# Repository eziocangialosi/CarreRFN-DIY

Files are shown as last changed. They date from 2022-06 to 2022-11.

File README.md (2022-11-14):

# CarreRFN-DIY

Reproduction of an french railway signal at the 1/2 scale

# French Section (English section below) :
## Avancement du projet :
Le projet est aujourd'hui terminé ! Tout les feux sont montés et cablés. La décoration est également terminée
et la partie "intelligence" est installée et fonctionnelle.
NB : Le support qui permet de fixer le signal au mur ne sera pas référencé car adapté à mon mur.
Il vous faudra donc adapter le support à votre mur par exemple.

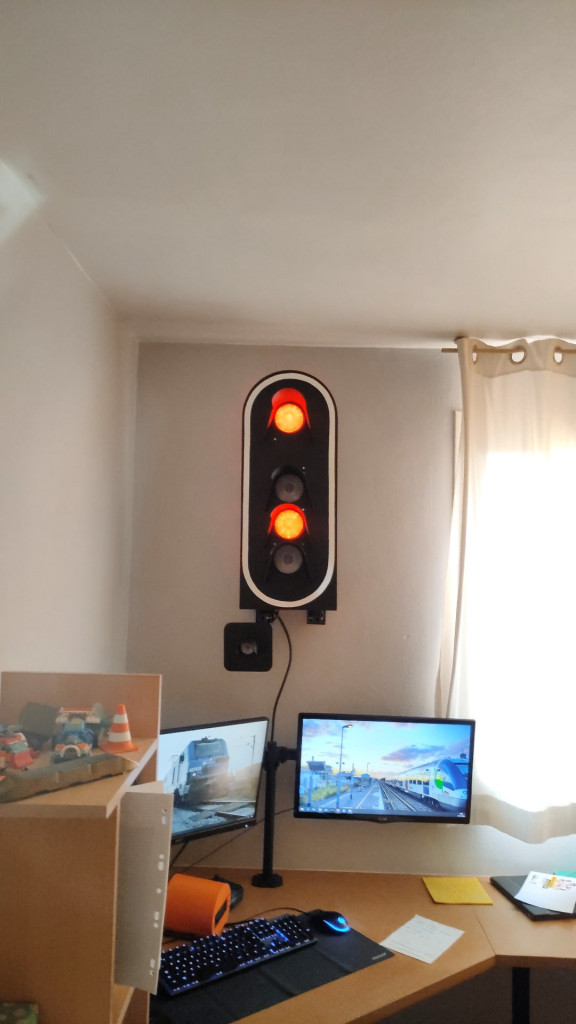
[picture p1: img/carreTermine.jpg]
Photo du carre terminé et fixé


## Objectif :
Reproduction d'un signal typique du réseau ferroviaire français à but décoratif
et à l'échelle 1/2.
Plus précisément, un "carré" à 5 feux (dont 1 bouché) plus un oeuilleton.
Le signal sera commandée à partir d'un ESP8266 et à l'aide d'une interface web, le tout
communiquant grâce au protocole MQTT.

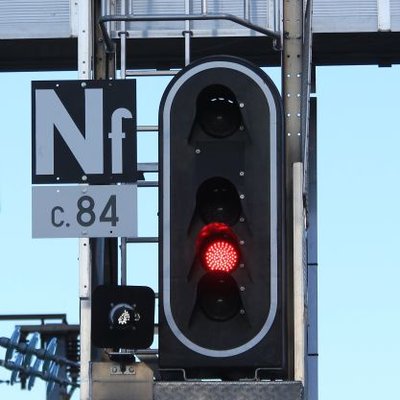
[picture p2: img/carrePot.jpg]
Photo d'un "carré" sur une potence


## Mise en plan du projet :
La première phase du projet à été sa mise en plan et modélisation 3D sous SolidWorks.

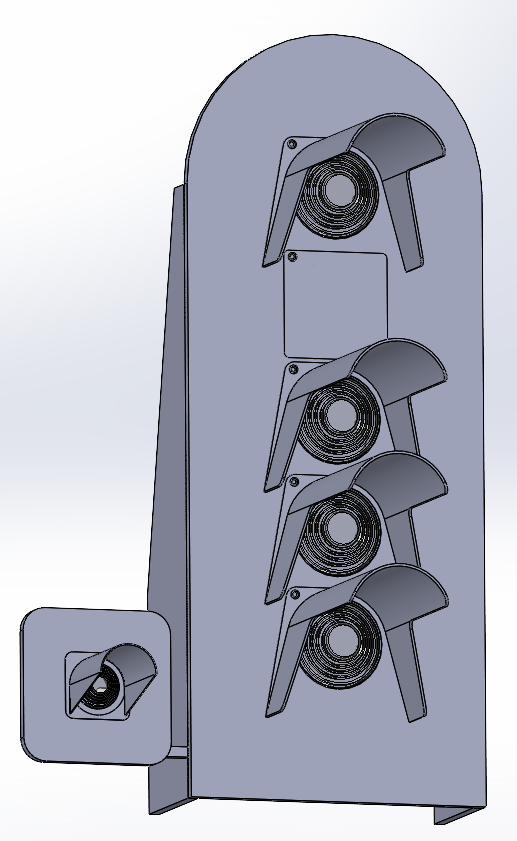
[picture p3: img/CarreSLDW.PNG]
Screenshot de la modélisation sous Soldiworks


Cette mise en plan à été faite partir de documents et plans trouvés sur internet
(rassemblés dans le dossier data)

## Réalisation :
### Cible et Oeuilleton :
La Cible et l'Oeuilleton ont été réalisés en bois puis peints en noir mat avec une bombe à peinture.

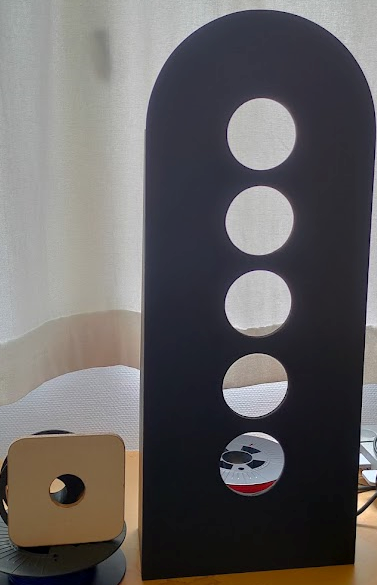
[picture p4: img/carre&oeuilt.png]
Photo de l'Oeuilleton et de la Cible


### Casquettes, diffuseurs et fonds de feux
Les casquettes qui protègent les feux ont étés réalisées grâce à l'impression 3D en PLA.
Il en est de même pour les fonds de feux. Les diffuseurs vont probalement être réalisés
également via l'impression 3D mais en PETG transparent.

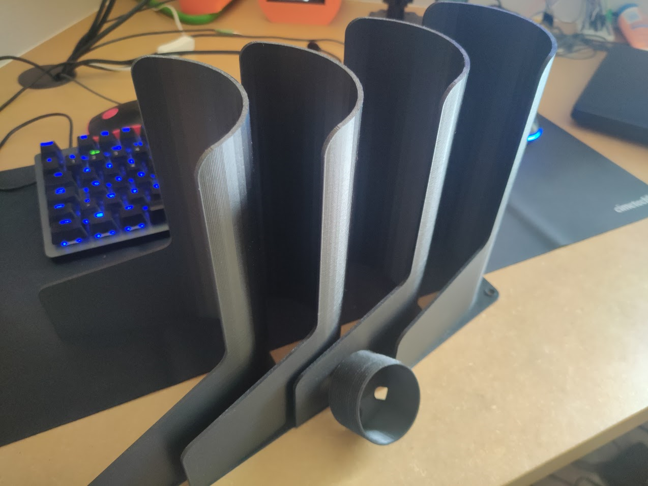
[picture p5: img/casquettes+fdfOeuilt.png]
Photo des casquettes et fond de feu de l'oeuilleton


### Lumière et partie éléctronique
L'électronique du projet s'articule autour d'un ESP8266. Du strip led adressable (WS2811) va
être utilisé faire l'allumage des feux.
NB : Des photos de la connectique choisie pour connecter les feux au faisceau éléctrique et du cablage à l'interieur des feux
sont disponibles dans le dossier "./img".

### Décorations
Le principal point de décoration sur le projet, est le contour blanc de la cible. Celui ci à été réalisé
avec du vinyle autocollant blanc découpé au scalpel. Le rendu est plutôt satisfaisant bien que un découpage
à la CNC aurait été plus propre.

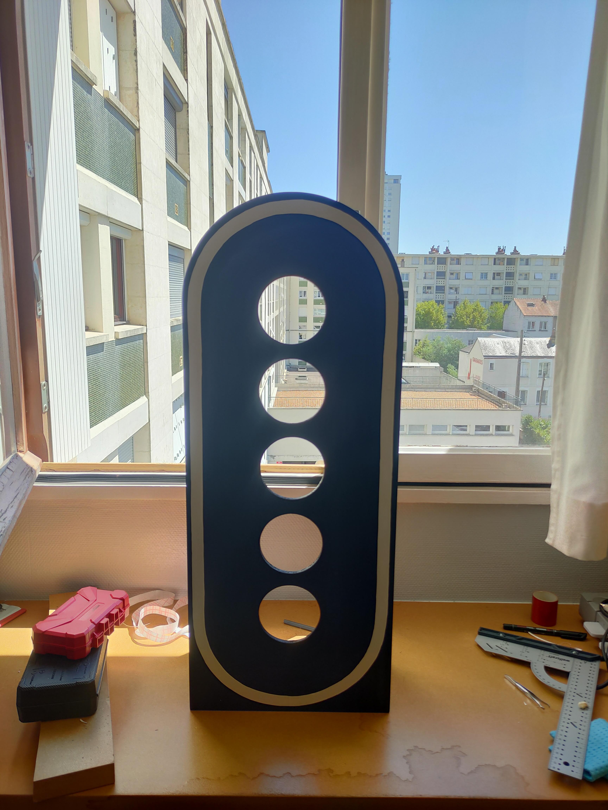
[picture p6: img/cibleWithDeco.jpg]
Photo de la cible décorée


# English Section :
## Project progreess :
Now, the project is completely finished, all the lights are mounted and wired. The decoration is also finished
and the "intelligence" part is installed and functional.
NB : The support that allows the signal to be fixed to the wall will not be referenced because it is suitable for my wall.
You will therefore have to adapt the support to your wall, for example.

Pic of the terminated project

## Goal :
Reproduction of a typical french railway network signal for decorative purposes and at the 1/2 scale.
In details, that's a "carré" with 5 lights (including 1 blocked) and one eyecup.
The signal will be command from an ESP8266 and with a web interface, all communicating through the MQTT protocol.

a carré's pic on a gallow

## Project Plan :
The first step of the project was its drawing and 3D modeling under SolidWorks.

Screenshot of 3D modeling under SolidWorks

The drawing was made from docs and plans found on internet (gathered in the data folder).

## Construction :
### Target and eyecup :
The target and the eyecup are made of wood and painted black with spray bomb.

Pic of the target and the eyecup

### Caps, diffusers and lightboxes
The caps protecting lights are made thanks to PLA 3D printing. That's the same process used for lightboxes.
The diffusers will probably also be made in 3D printing but in transparent PETG.

Pic of caps and eyecup's lightbox

### Lights and electronic part
The electronic is based around an ESP8266. For the lights, an addressable led strip (WS2811) will be used.
NB: Photos of the connectors chosen to connect the lights to the electrical harness and of the wiring inside the lights
are available in the "./img" folder.

### Decorations
The principal decoration point on the project is the blank outline of the target. This one was made
with scalpel-cut white self-adhesive vinyl. The rendering is rather satisfactory although a cutout
at the CNC would have been cleaner.

Photo of the cible decorated

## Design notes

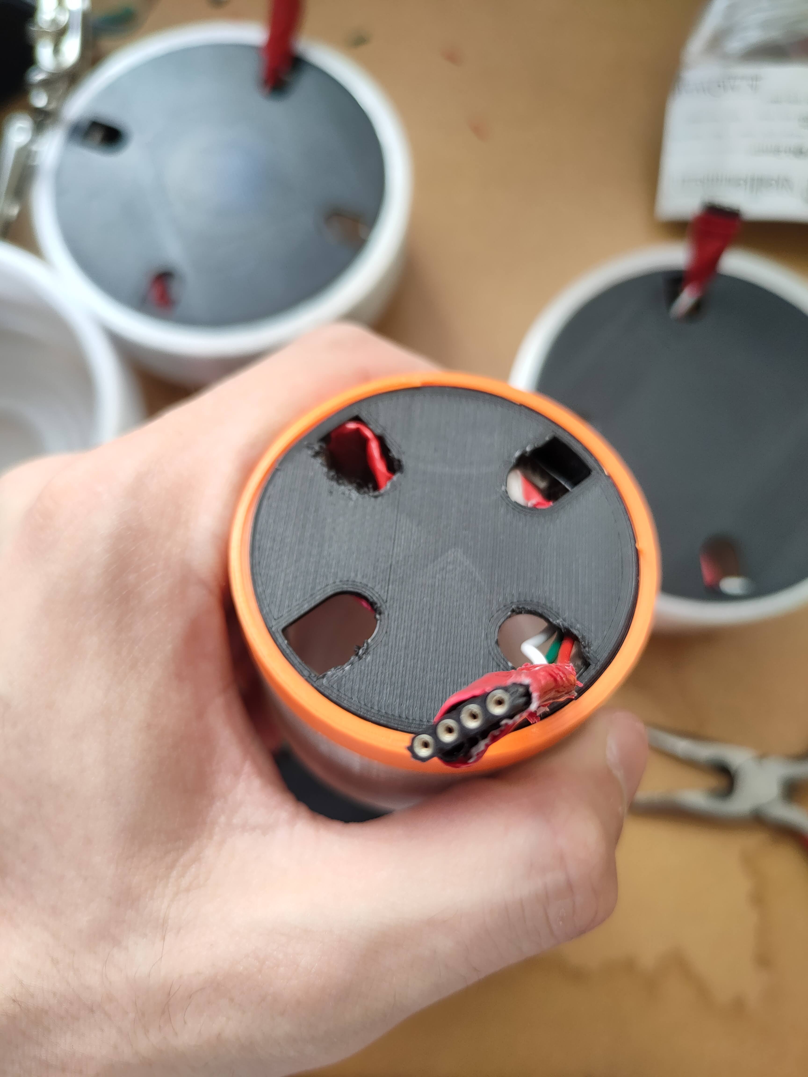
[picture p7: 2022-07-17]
img/LightConnector.jpg

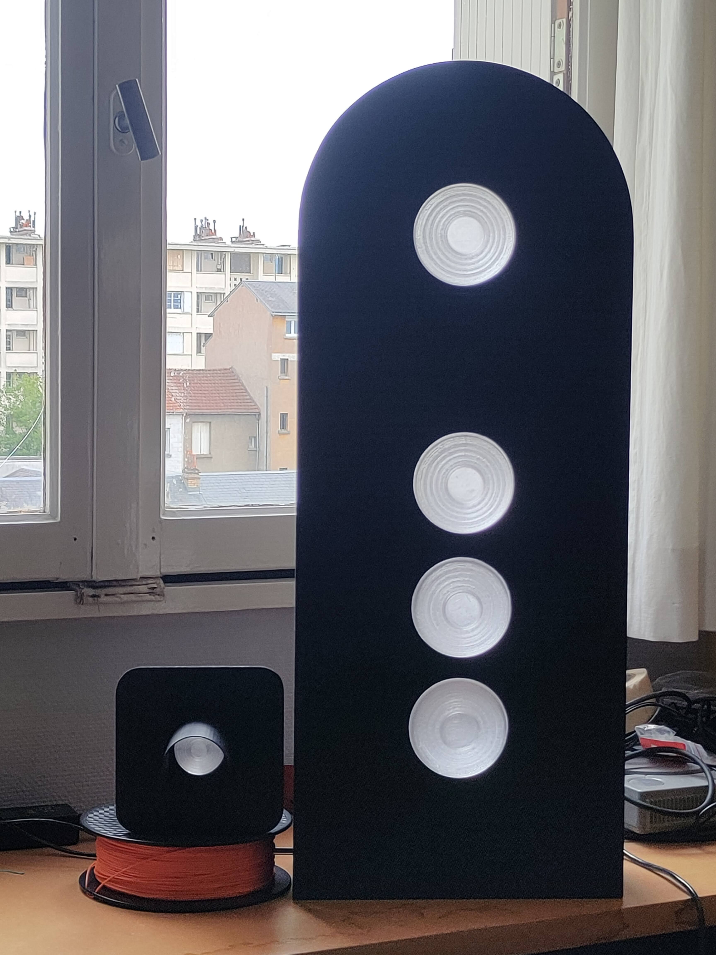
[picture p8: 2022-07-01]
img/avcmentfinjuin.jpg

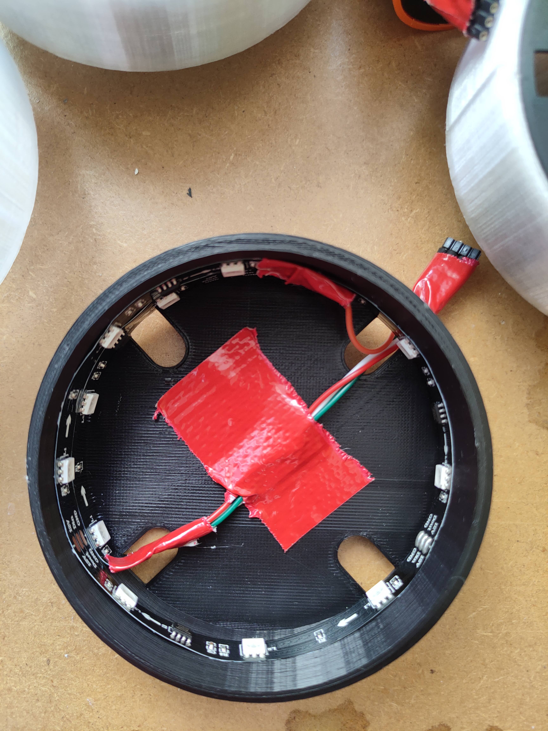
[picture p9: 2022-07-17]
img/InsideLight.jpg

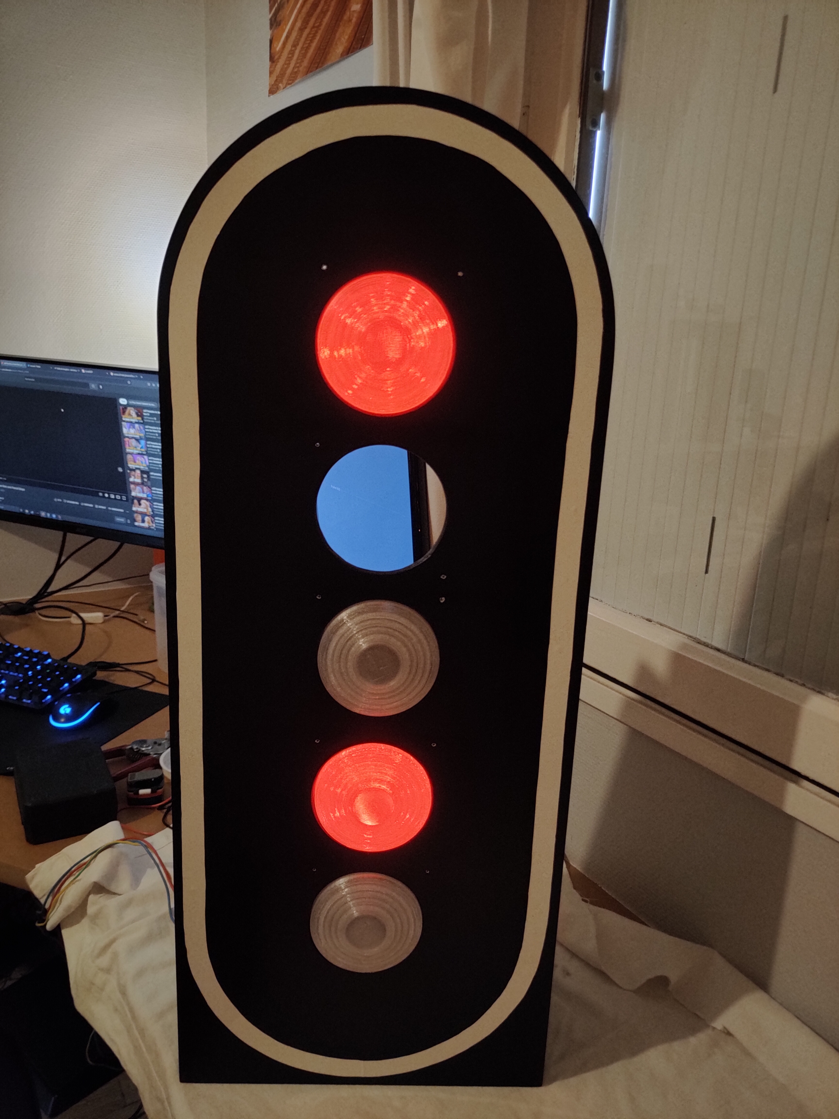
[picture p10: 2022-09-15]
img/cible98.jpg

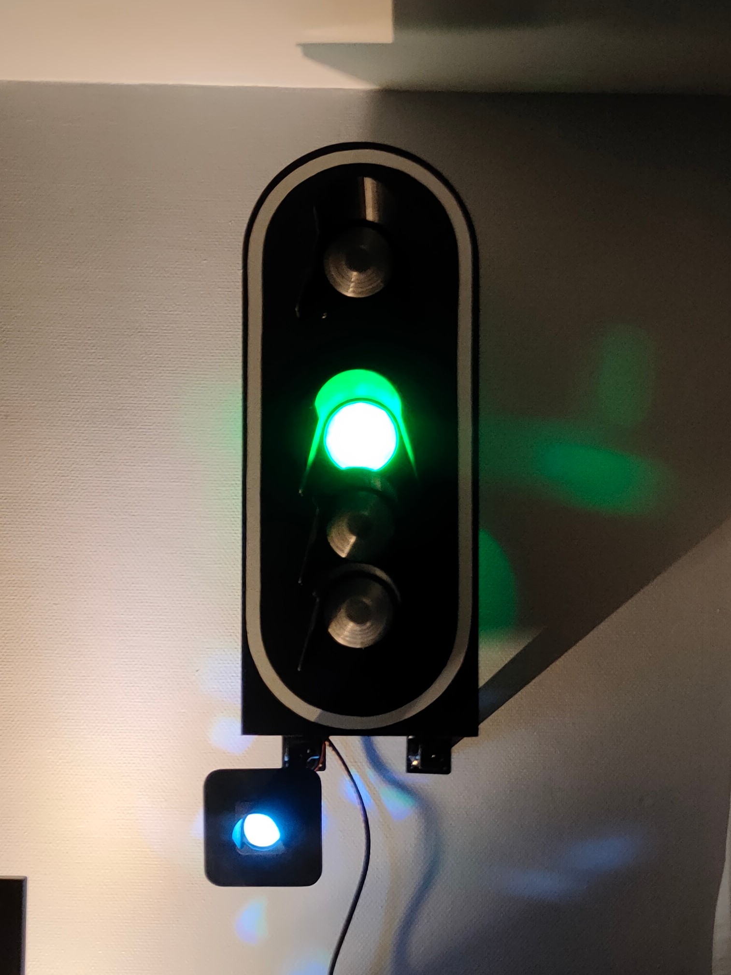
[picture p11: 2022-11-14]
img/termineVL.jpg

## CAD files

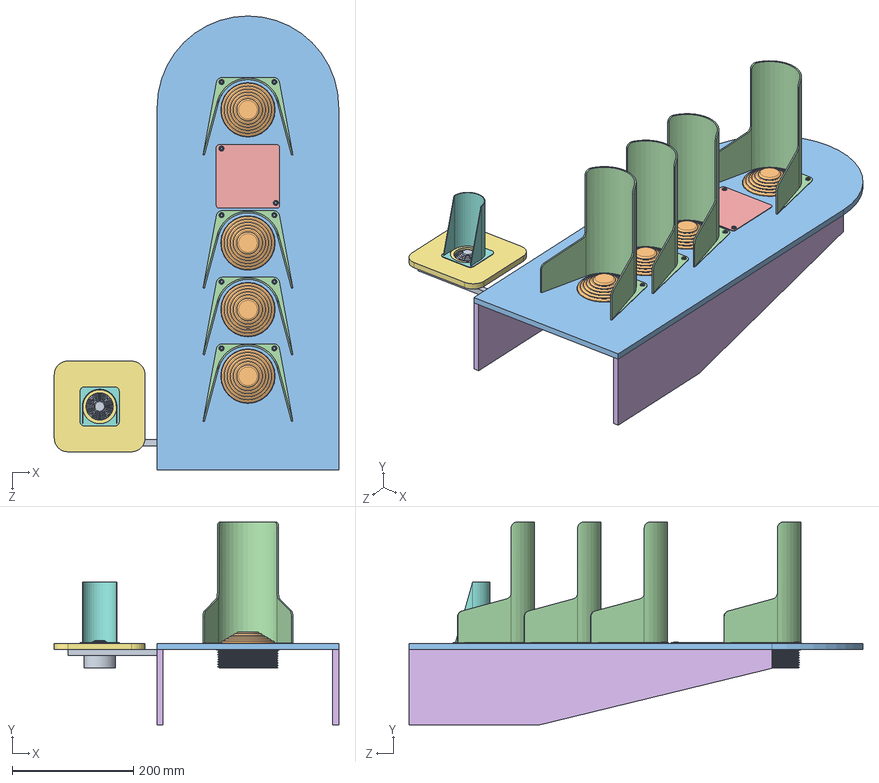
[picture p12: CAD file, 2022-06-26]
3DModels/SLDW Files/SignalRFN1,5.SLDASM
470.0 x 335.3 x 750.0 mm
CibleTypeB
CacheSoleil x 4
BoucheTrou
SideCible x 2
DiffuseurCible x 4
CibleOeuilleton
CasquetteOeuilleton
TasseauOeuilleton
FondLED x 3
DiffuseurOeuilleton
FondLEDOeuilleton

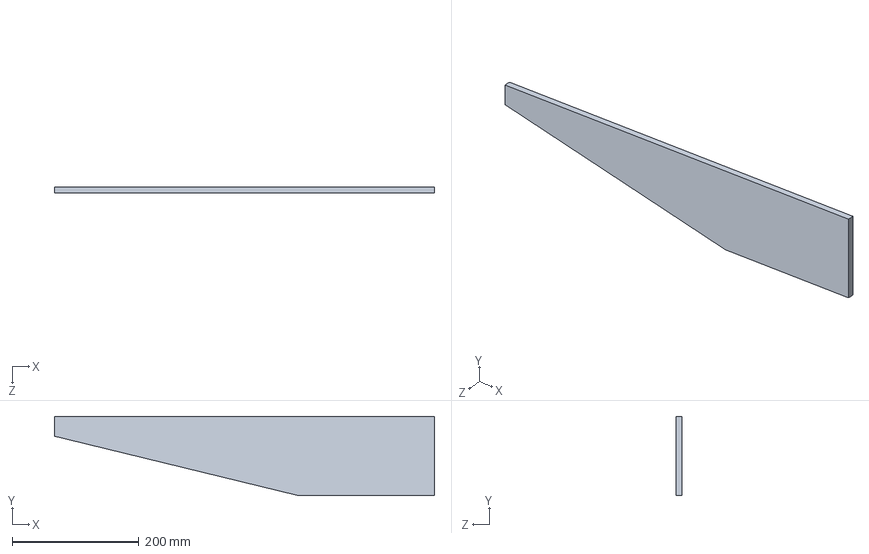
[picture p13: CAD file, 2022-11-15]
3DModels/SLDW Files/SideCible.SLDPRT
600.0 x 125.0 x 10.0 mm

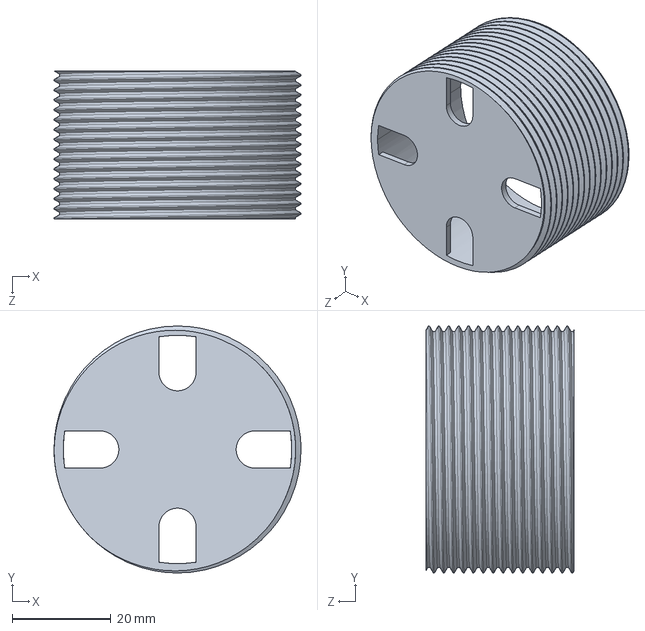
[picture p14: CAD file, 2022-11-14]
3DModels/STEP Files/FondLEDOeuilleton.STEP
50.0 x 50.0 x 30.0 mm

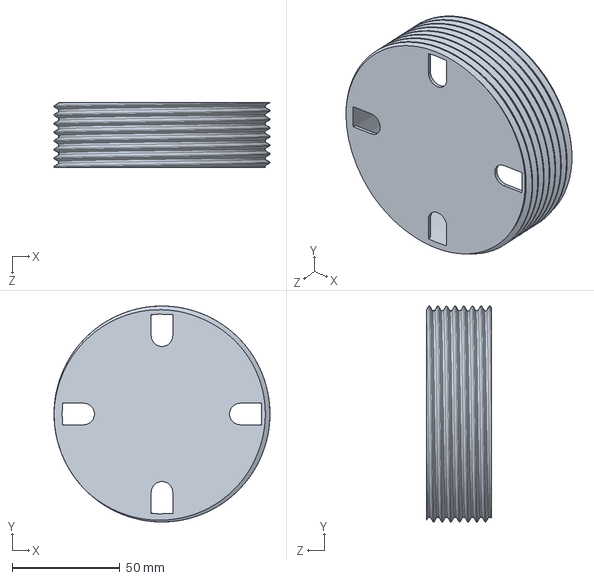
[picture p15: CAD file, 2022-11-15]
3DModels/SLDW Files/FondLED.SLDPRT
100.0 x 100.0 x 30.0 mm

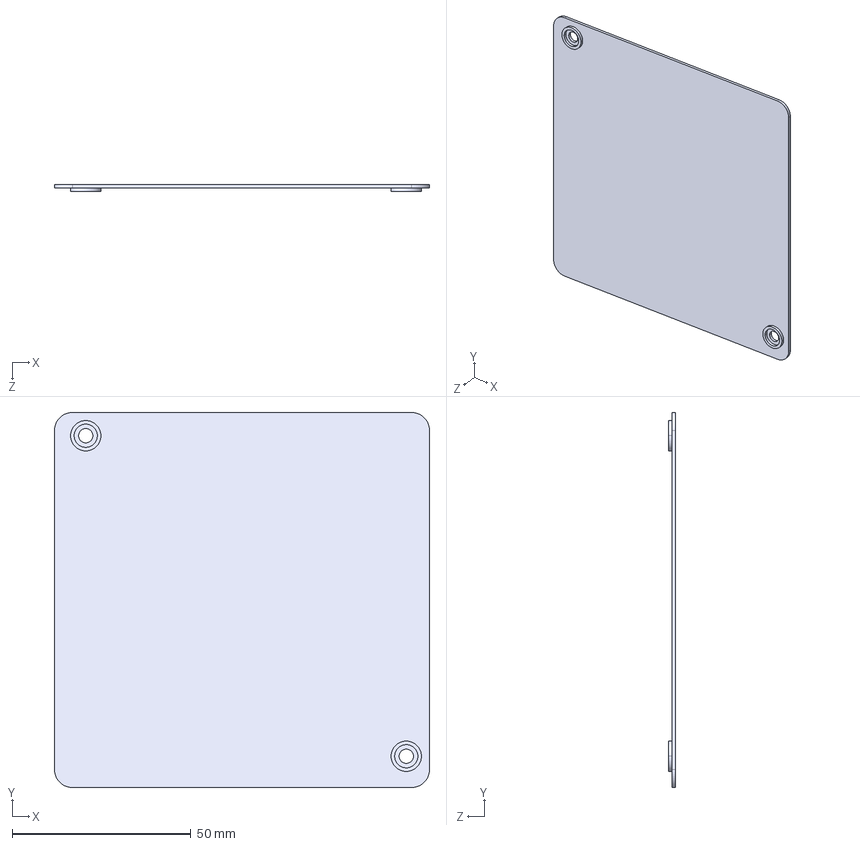
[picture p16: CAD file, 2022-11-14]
3DModels/STEP Files/BoucheTrou.STEP
105.0 x 105.0 x 2.00 mm

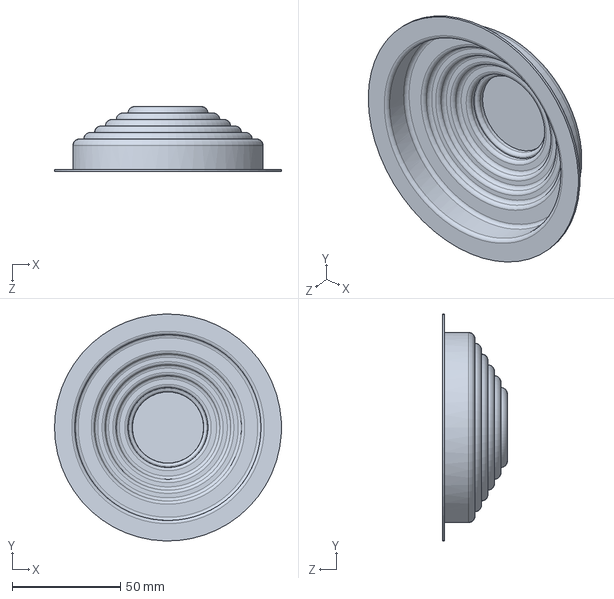
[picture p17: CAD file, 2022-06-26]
3DModels/SLDW Files/DiffuseurCible.SLDPRT
105.0 x 105.0 x 30.0 mm

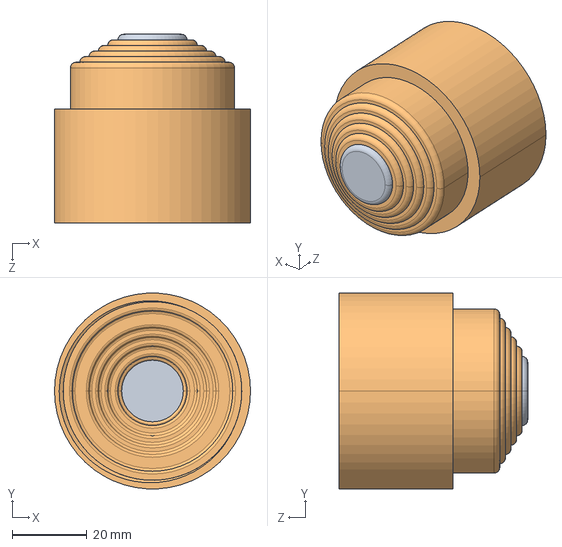
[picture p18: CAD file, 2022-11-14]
3DModels/STEP Files/DiffuseurOeuilleton.STEP
52.5 x 52.4 x 50.5 mm

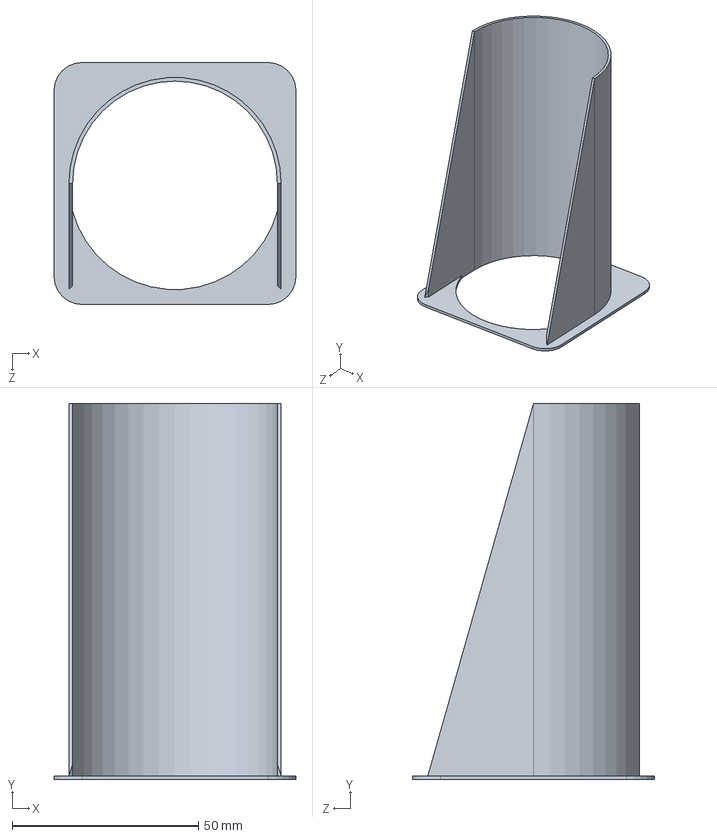
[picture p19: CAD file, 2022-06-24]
3DModels/SLDW Files/CasquetteOeuilleton.SLDPRT
65.0 x 101.0 x 65.0 mm

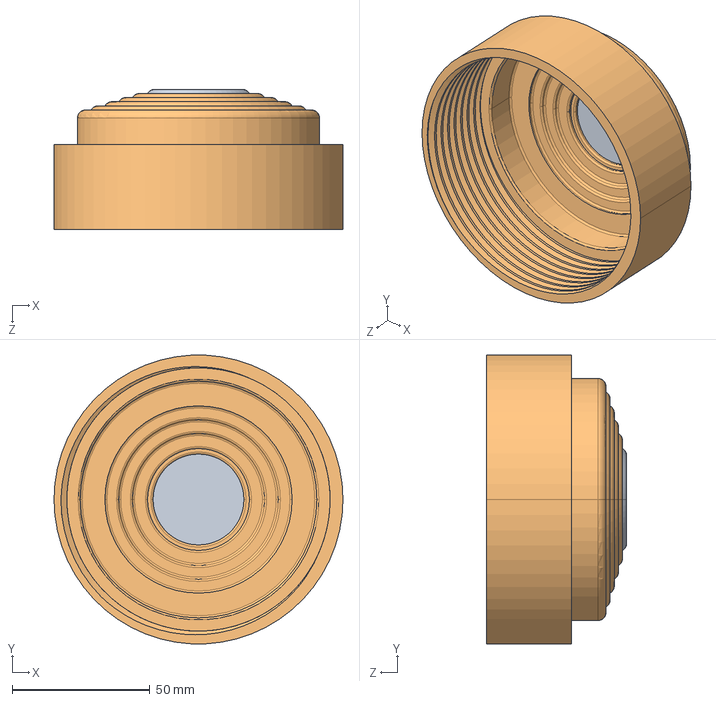
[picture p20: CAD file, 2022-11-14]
3DModels/STEP Files/DiffuseurCible.STEP
105.0 x 104.8 x 51.0 mm

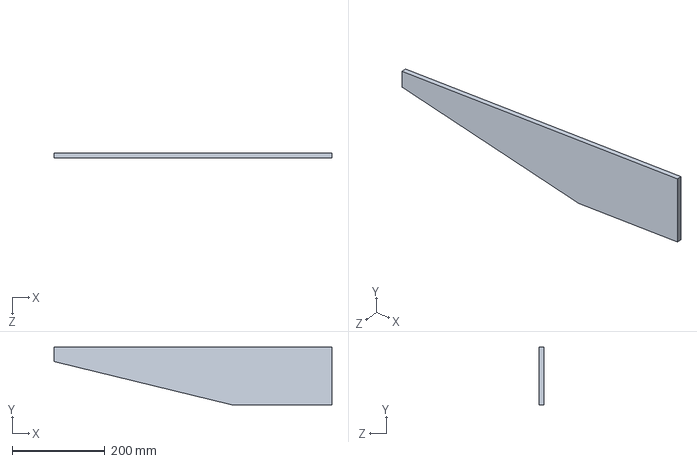
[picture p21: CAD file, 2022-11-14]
3DModels/STEP Files/SideCible.STEP
600.0 x 125.0 x 10.0 mm

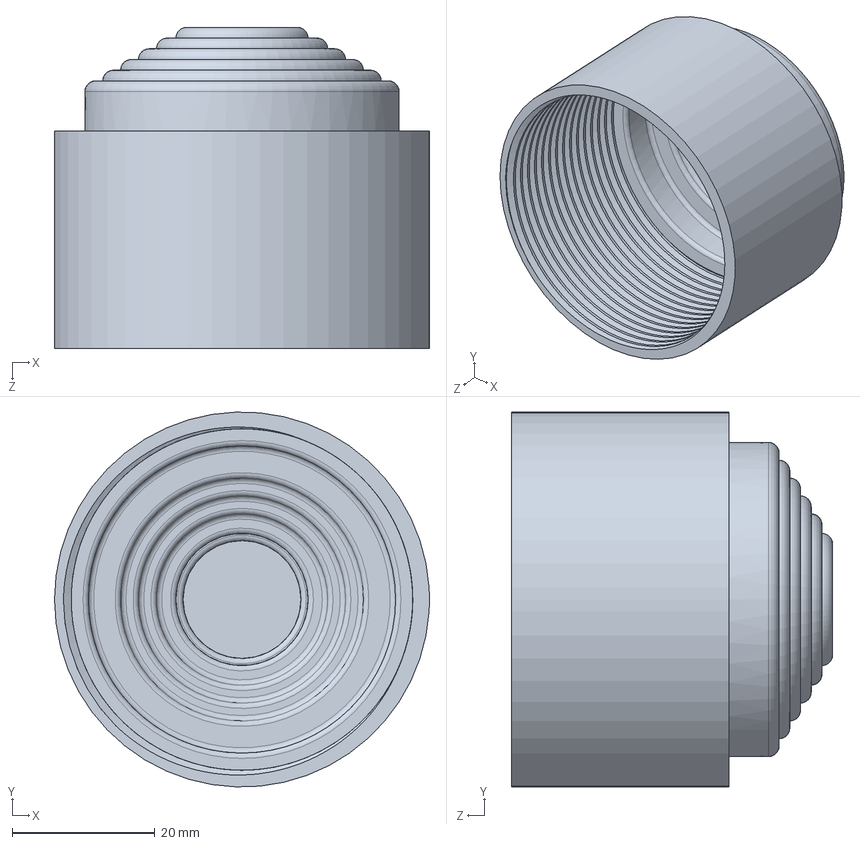
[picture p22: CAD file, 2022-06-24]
3DModels/SLDW Files/DiffuseurOeuilleton.SLDPRT
52.5 x 52.5 x 45.0 mm

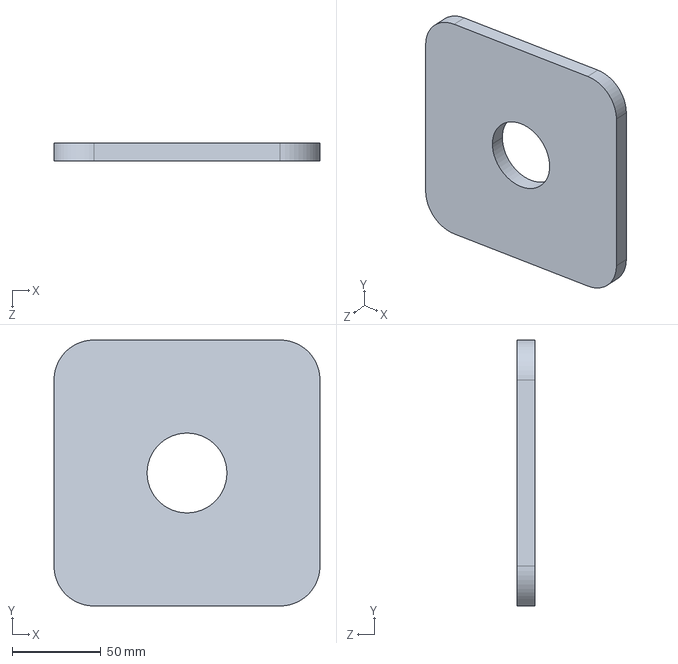
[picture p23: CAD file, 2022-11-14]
3DModels/STEP Files/CibleOeuilleton.STEP
150.0 x 150.0 x 10.0 mm

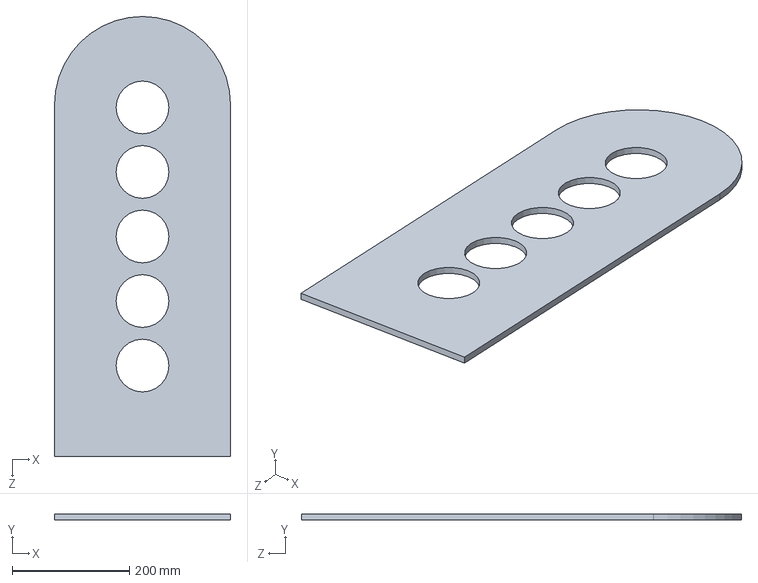
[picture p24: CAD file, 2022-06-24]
3DModels/SLDW Files/CibleTypeB.SLDPRT
300.0 x 10.0 x 750.0 mm

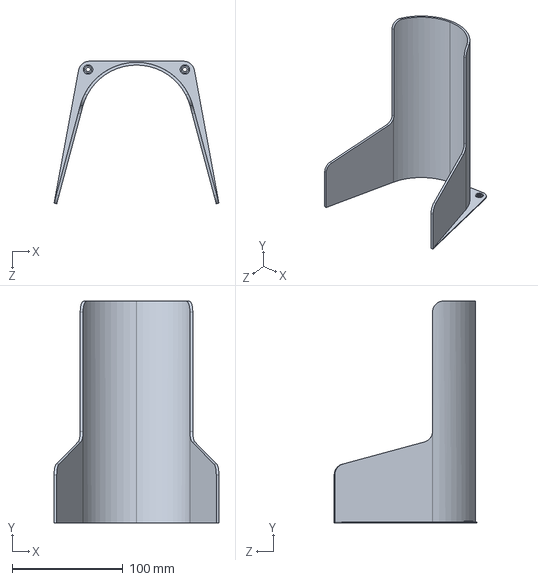
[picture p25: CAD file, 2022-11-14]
3DModels/STEP Files/CacheSoleil.STEP
148.5 x 200.0 x 128.5 mm

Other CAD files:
3DModels/STEP Files/FondLED.STEP
3DModels/SLDW Files/TasseauOeuilleton.SLDPRT
3DModels/SLDW Files/CacheSoleil.SLDPRT
3DModels/STEP Files/CasquetteOeuilleton.STEP
3DModels/SLDW Files/BoucheTrou.SLDPRT
3DModels/SLDW Files/CibleOeuilleton.SLDDRW
3DModels/SLDW Files/CibleOeuilleton.SLDPRT
3DModels/SLDW Files/FondLEDOeuilleton.SLDPRT
3DModels/SLDW Files/SignalRFN1,5.SLDDRW
3DModels/STEP Files/CibleTypeB.STEP
3DModels/STL Files/BoucheTrou.STL
3DModels/STL Files/CacheSoleil.STL
3DModels/STL Files/CasquetteOeuilleton.STL
3DModels/STL Files/CibleOeuilleton.STL
3DModels/STL Files/CibleTypeB.STL
3DModels/STL Files/DiffuseurCible.STL
3DModels/STL Files/DiffuseurOeuilleton.STL
3DModels/STL Files/FondLED.STL
3DModels/STL Files/FondLEDOeuilleton.STL
3DModels/STL Files/SideCible.STL

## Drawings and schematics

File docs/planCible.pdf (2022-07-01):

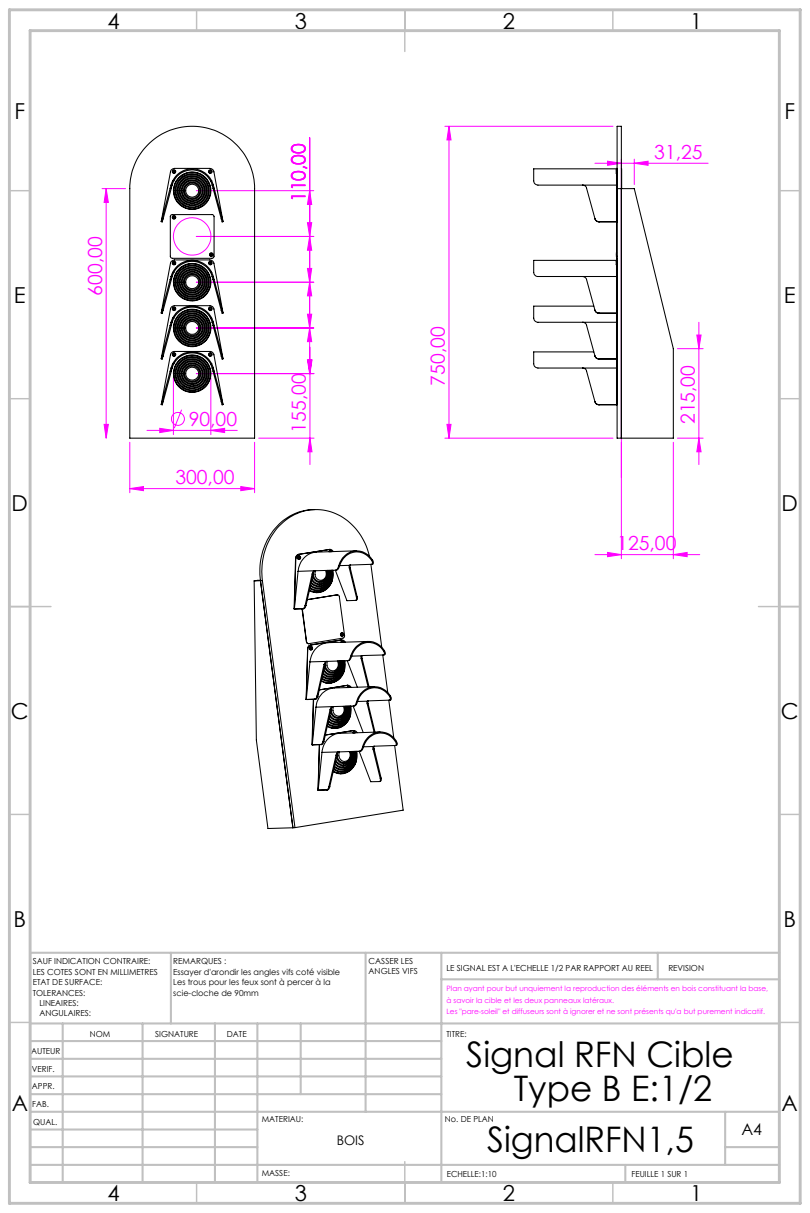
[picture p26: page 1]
CASSER LES ANGLES VIFS; LE SIGNAL EST A L'ECHELLE 1/2 PAR RAPPORT AU REEL; REVISION; ECHELLE:1:10; FEUILLE 1 SUR 1

SAUF INDICATION CONTRAIRE:
LES COTES SONT EN MILLIMETRES
ETAT DE SURFACE:
TOLERANCES:
LINEAIRES:
ANGULAIRES:

REMARQUES :
Essayer d'arondir les angles vifs coté visible
Les trous pour les feux sont à percer à la
scie-cloche de 90mm

Plan ayant pour but unquiement la reproduction des éléments en bois constituant la base,
à savoir la cible et les deux panneaux latéraux.
Les "pare-soleil" et diffuseurs sont à ignorer et ne sont présents qu'a but purement indicatif.

NOM | SIGNATURE | DATE | | | | TITRE: Signal RFN Cible Type B E:1/2

AUTEUR
VERIF.
APPR.
FAB.
QUAL. | | | | MATERIAU: BOIS | No. DE PLAN SignalRFN1,5 | A4

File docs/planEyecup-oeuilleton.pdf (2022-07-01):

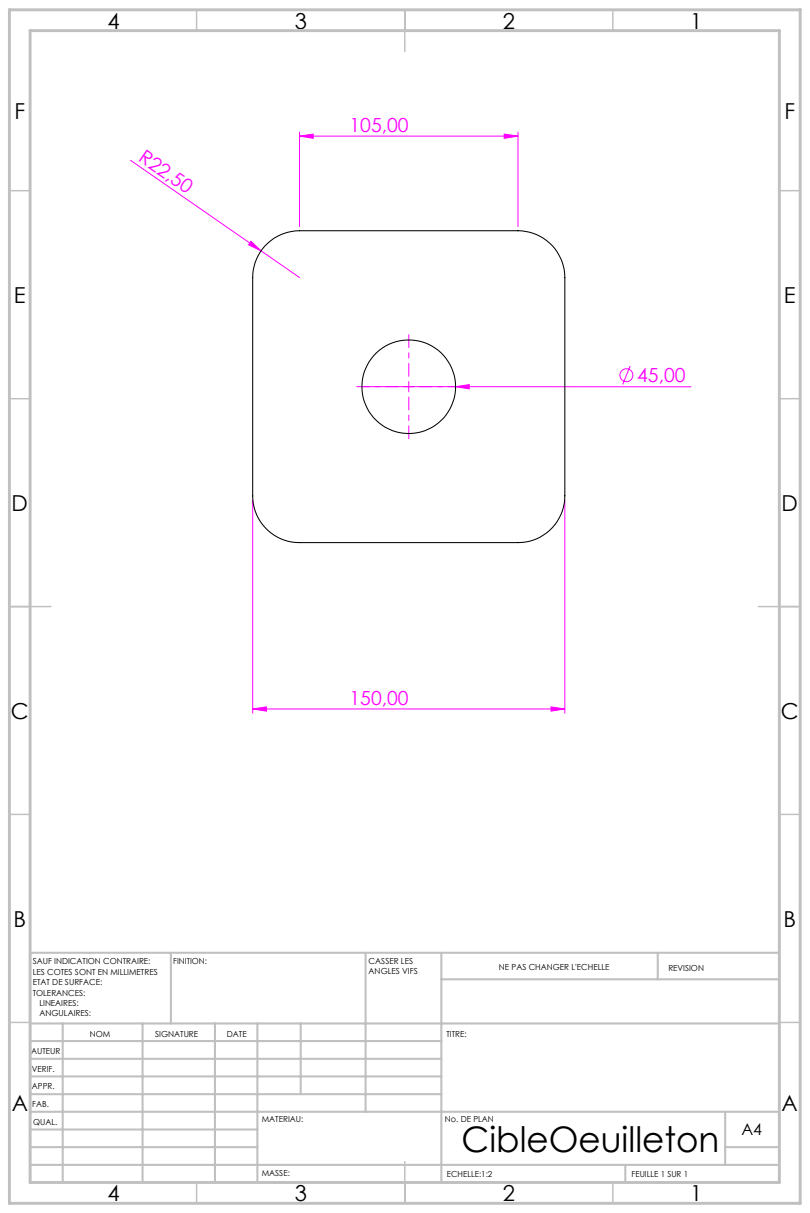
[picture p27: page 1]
FINITION:; CASSER LES; ANGLES VIFS; NE PAS CHANGER L'ECHELLE; REVISION; ECHELLE:1:2; FEUILLE 1 SUR 1

SAUF INDICATION CONTRAIRE:
LES COTES SONT EN MILLIMETRES
ETAT DE SURFACE:
TOLERANCES:
LINEAIRES:
ANGULAIRES:

NOM | SIGNATURE | DATE | | | | TITRE:

AUTEUR
VERIF.
APPR.
FAB.
QUAL. | | | | MATERIAU: | No. DE PLAN CibleOeuilleton | A4

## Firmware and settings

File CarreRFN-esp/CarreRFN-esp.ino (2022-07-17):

//CarreMQTT Version 1.0 Beta, Ezio Cangialosi, 2022

#include <ESP8266WiFi.h>
#include <PubSubClient.h>
#include <Adafruit_NeoPixel.h>

#define OUTTOPIC  "CarreMQTT/TX"
#define INTOPIC   "CarreMQTT/RX"
#define ERRORSTR  "Error when trying to understand message or no corresponding action."

#define PINSTRIP 5
#define NBRPIXELS 18

#define NBRIMAGES 7
#define NBRPIXELS_PER_IMG 8

const char* RECO_PAYLOAD[10] = {"P" , "VL", "ACLI", "A", "SCLI", "S", "C", "GetSig", "SelfReboot", "Ping"}; 
const byte SPECIFIC_LED[NBRIMAGES] = {  3,   2,   3,   2,   3,   2,   0}; //2 = Oeuilleton, 1 = Cli, 3 = les deux, 0 = aucun
const byte LED_COL[3][NBRIMAGES] = {{   0,   0, 215, 215, 255, 255, 255},//Rouge
                                    {   0,   0,   0,   0,   0,   0,   0},//Bleu
                                    { 255, 255,  90,  90,   0,   0,   0}};//Vert
const byte NUM_LED_PIXEL[NBRPIXELS_PER_IMG][NBRIMAGES] = {{ 10,  10,   2,   2,   6,   6,   6},
                                                          { 11,  11,   3,   3,   7,   7,   7},
                                                          { 12,  12,   4,   4,   8,   8,   8},
                                                          { 13,  13,   5,   5,   9,   9,   9},
                                                          {255, 255, 255, 255, 255, 255,  14},
                                                          {255, 255, 255, 255, 255, 255,  15},
                                                          {255, 255, 255, 255, 255, 255,  16},
                                                          {255, 255, 255, 255, 255, 255,  17}};
                           
const byte RGB_OEUIT[3] = {255,255,255};
#define DELAY_CLI 500
const byte OEUIT_PIXELS[2] = {0,1}; 

bool g_flagCli = false;

const char* ssid = "YOUR SSID";
const char* password = "YOUR WIFI PASSWORD";
const char* mqtt_server = "YOUR BROKER";

byte g_curMode = 6;

long g_lastAttemptLed = 0;

WiFiClient espClient;
PubSubClient client(espClient);
Adafruit_NeoPixel strip = Adafruit_NeoPixel(NBRPIXELS, PINSTRIP, NEO_GRB + NEO_KHZ800);

long lastReconnectAttempt = 0;

void(* resetFunc) (void) = 0;

void setup_wifi() {

  delay(10);
  // We start by connecting to a WiFi network
  Serial.println();
  Serial.print("Connecting to ");
  Serial.println(ssid);

  WiFi.mode(WIFI_STA);
  WiFi.begin(ssid, password);

  while (WiFi.status() != WL_CONNECTED) {
    delay(500);
    Serial.print(".");
  }

  randomSeed(micros());

  Serial.println("");
  Serial.println("WiFi connected");
  Serial.println("IP address: ");
  Serial.println(WiFi.localIP());
}

void callback(char* topic, byte* payload, unsigned int length) {//Est appelée automatiquement quand un nouveau message est détecté sur un topic
  String msg="";
  Serial.print("Message arrived [");
  Serial.print(topic);
  Serial.print("] ");
  for (int i=0;i<length;i++) {
    Serial.print((char)payload[i]);
    msg +=(char)payload[i];//On rentre le message dans une string pour le traiter en suite
  }
  master(msg);//Fonction de traitement principale
  Serial.println();
}

boolean reconnect() {
  Serial.print("Attempting MQTT connection...");
  // On essaye de se connecter en se nommant WakeOnDuino
  if (client.connect("CarreMQTT")) {
    Serial.println("connected");
    //Une fois connectée on publie un msg sur le topic de status
    client.publish(OUTTOPIC,"CarreMQTT Version 1.0 Beta Connected");
    //Et on écoute sur le topic de commande
    client.subscribe(INTOPIC);
    return client.connected();
  }
  else {
    Serial.print("failed, rc=");
    Serial.print(client.state());
    Serial.println(" try again in 5 seconds");
  }
}

void setup() {
  Serial.begin (9600); //initialisation de communication série
  strip.begin(); //Init Strip led
  delay(10);
  setAllStripBlank();
  strip.show();
  setup_wifi();
  client.setServer(mqtt_server, 1883);//Démarrage serveur mqtt sur port 1883
  client.setCallback(callback);//Ce qui permet de récupérer les messages entrants

  Serial.println("CarreMQTT Version 1.0 Beta");

  delay(1000);

  lastReconnectAttempt = 0;

  Serial.println("\nWait for MQTT Broker connection");
}

void loop(){
  if (!client.connected()) {//Si on n'est pas connecté au Broker
    long now = millis();
    if (now - lastReconnectAttempt > 5000) {//Un essai toutes les 5secs
      lastReconnectAttempt = now;
      // Attempt to reconnect
      if (reconnect()) {
        lastReconnectAttempt = 0;
      }
    }
  }
  else {
    // Client connected
    client.loop();
    if(millis() - g_lastAttemptLed > DELAY_CLI){
      g_lastAttemptLed = millis();
      Serial.println("Do Led");
      doLed();
    }
  }
}

void master(String msg){
  for(byte i = 0; i < 10; i++){
    if(msg == RECO_PAYLOAD[i]){
      if(i == 7){
        returnSig();
      }else if (i == 8){
        selfReboot();
      }else if (i == 9){
        pingReceived();
      }else{
        g_lastAttemptLed = 0;
        g_curMode = i;
      }
    }
  }
}

void doLed(){
  setAllStripBlank();
  if(SPECIFIC_LED[g_curMode] & 0x02){
    strip.setPixelColor(OEUIT_PIXELS[0], strip.Color(RGB_OEUIT[0], RGB_OEUIT[1], RGB_OEUIT[2]));
    if(OEUIT_PIXELS[1] < NBRPIXELS){
      strip.setPixelColor(OEUIT_PIXELS[1], strip.Color(RGB_OEUIT[0], RGB_OEUIT[1], RGB_OEUIT[2]));
    }
  }
  for(unsigned int i = 0; i < NBRPIXELS_PER_IMG; i++){
    if(NUM_LED_PIXEL[i][g_curMode] < NBRPIXELS && !g_flagCli){
      strip.setPixelColor(NUM_LED_PIXEL[i][g_curMode], strip.Color(LED_COL[0][g_curMode], LED_COL[1][g_curMode], LED_COL[2][g_curMode]));
      Serial.println("Set lum");
    }
  }
  if(SPECIFIC_LED[g_curMode] & 0x01){
    g_flagCli = !g_flagCli;
  }else{
    g_flagCli = false;
  }
  
  strip.show();
}

void selfReboot(){
  Serial.println("Ordre de redémarrage reçu\nExecution dans 5 secondes");
  client.publish(OUTTOPIC,"Redémarrage demandé, execution dans 5 secondes...");
  delay(5000);
  Serial.println("Redémarrage");
  client.publish(OUTTOPIC,"Rebooting, See you soon world !");
  delay(100);
  resetFunc();
}

void returnSig(){
  Serial.println("Demande de retour de l'image affichée");
  client.publish(OUTTOPIC,RECO_PAYLOAD[g_curMode]);
  Serial.println("Image actuelle envoyée");
  delay(100);
}

void setAllStripBlank(){
  for(unsigned int i = 0; i < NBRPIXELS ; i++){
    strip.setPixelColor(i, strip.Color(0,0,0));
  }
}

void pingReceived(){
  Serial.println("Ping reçu, renvoi d'un 'pong'");
  client.publish(OUTTOPIC,"Pong");
  delay(10);
}

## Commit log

2022-06-24 Add all 3D Models to the repo
    [BoucheTrou.SLDPRT, CacheSoleil.SLDPRT, CasquetteOeuilleton.SLDPRT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]
2022-06-26 Update eyecup's diffuser to it be more transparent
    [DiffuseurCible.SLDPRT, SignalRFN1,5.SLDASM]
2022-06-27 Correction of images options
    Images corrected :
    - ACLI --> Cli + Oeuilt
    - A --> Oeuilt
    - SCLI --> Cli + Oeuilt
    [CarreRFN-esp.ino]
2022-06-28 Replace classic entries by defines and add a mask verif for options
    [CarreRFN-esp.ino]
2022-07-17 Allow arduino code to work with 4pixels by light
    The arduino can now manage 4 pixels for each light (8 for each image because of the "carré")
2022-07-17 Update the readme with current progression
2022-09-15 Update readme with current progression
2022-11-14 Add STEP converted files to 3DModels directory
    [BoucheTrou.SLDPRT, BoucheTrou.STEP, CacheSoleil.SLDPRT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]
2022-11-15 Add STL converted files and fix the display bug for FondLED.SLDPRT
    [BoucheTrou.STL, CacheSoleil.STL, CasquetteOeuilleton.STL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]
